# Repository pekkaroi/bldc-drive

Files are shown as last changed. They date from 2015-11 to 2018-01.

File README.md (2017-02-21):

# bldc-drive

This is a project developing a simple BLDC servo controller. It is based on an STM32F103 microcontroller.

Some parts, especially the PID control loop is based on development done by user mcm_xyz in cnczone.com forum. Thank you! Check the thread http://www.cnczone.com/forums/open-source-controller-boards/283428-cnc.html 

## Disclaimer
This software and hardware is provided "AS IS", WITHOUT ANY WARRANTY. The software is released under GPL v2. Authors accept no liability for any harm or loss resulting from use of this hardware or software.

## Authors & Contributors
* original Software by mcm_xyz from cnczone
* first Version of Hardware&Software in a Git-repo from pekkaroi via https://github.com/pekkaroi
* Schematic-additions and fork by Philipp Hörauf via https://github.com/Virtex7

## Firmware
Firmware is a work-in-progress (and will be for a while :), however following features are included:
* Trapezoidal BLDC commutation using either HALL sensors or quadrature encoder.
* Step+Dir input interface with PID position control loop.
* PWM+Dir input interface in velocity mode.
* USART communitacation for configuration. Configuration settings saved to flash memory.
* TODO: Motor Test Mode to simply activate a Motor with a fixed frequency, no encoder needed

### Update 1st May 2016
Some updates to the firmware. 
* ADC current limiting implemented. Appears to work OK
* I created a quick and ugly Python gui for tuning
* Updated the PID loop to have feedfoward coefficients FF1 and FF2 (like LinuxCNC). This means that the PID output can be adjusted by the requested speed and the requested acceleration. This made the PID tuning a lot easier for me at least, I'm able to get a motor to follow the requested position very well also during acceleration and during constant drive.

## Hardware:
First prototype hardware is built and it is working well. However, there are couple of known issues:
* 6n137 optocoupler is not officially supporting 3.3V supply voltage which is used in the board. In reality they seem to work, but the optocoupler should be changed or additional levelshifting circuitry added on next revision. Also, the optocoupler input circuit supports only push-pull-type encoder output. Many encoders seem to have open drain output. :(
* Few connectors in the layout missed solder stop openings. They were bit painfull to solder. :)
* The current amplifier INA27x connection is wrong. The IN+ and IN- should be swapped.

### STATUS QUO:

Second hardware revision with the above findings fixed is published. There are no known issues, two servo drives are succesfully driving my CNC router. Pics and videos to come..

### HARDWARE TODOs:

* verify all part-values into the schematic

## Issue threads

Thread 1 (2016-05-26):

PID error of the project

lemonhdu, 2016-05-26:
Lucky to see this impressive protect, it is with a good framwork. I have tested it in the step mode with an encoder of 4000 PPR. But when I adjust the input signal about 60KHz, that means the speed is under 1000 RPM, the pid error will decrease from 8800 to about 6500, then it will jump bigger and bigger till the biggest pid error.So during this, the sound is also bigger and bigger, why does it happen?
Thanks.

pekkaroi, 2016-05-26:
Thanks for you comment, you are probably the first one to test my code apart from myself!

There is a setting called "encoder_counts_per_step". What value did you have there? I've set it to 10 by default. This means that for each step pulse, the requested position will go +/-10. So if you did not change the default and  then give 60kHz input, the requested speed is already 9000rpm which may be too much? Are you able to run a motor with slower speed?

lemonhdu, 2016-05-27:
Yeah, I set  "encoder_counts_per_step" with 1, so the real speed should be 900 RPM. Didn't you encounter this problem?

pekkaroi, 2016-05-27:
No I haven't encountered that. However I'm not quite sure if I understand the problem you have. You say that the pid error will decrease when this happens. I don't know what that means.. Shouldn't the pid error be close to zero when the drive is functioning properly, that way the requested position is close to the actual position? How do you monitor the pid_error when you run the motor? I published my tuning Python gui last night. It can be used to monitor pid error and other things as well.

lemonhdu, 2016-05-30:
Thank you. Yes, the pid error decresed first and increase later, I am trying the make certain of it. I also believe the program is correct, otherwise the error will not decrease. The encoder I used before is 1000 PPR, if I understand correctly the program makes the frequency quadruple. Now I bought a new one with 3600 PPR, that may mean real PPR will be as much as 14400. I see the program brief "8096 PPR max at the moment", so whether this means this encoder can't be used at present. I print the parameters with usart. Congraduation to your tuner, it will be easier for debugging~

lemonhdu, 2016-05-31:
Pekka, have you tested the highest speed in the step mode with the encoder, and how about the torque performance? And what's the encoder's  PPR?

pekkaroi, 2016-05-31:
First, about the encoder PPR. The number specified with the encoder is usually telling that how many quadrature pulses you will get per rotation. Every quadrature pulse includes A line rising, B rising, A falling and B falling. My firmware will increment the counter at each of those events, so yes, the PPR (also called CPR) seen by my firmware is four times the rating you often see on the label of the encoder. However, I have also seen that some encoders have their rating already multiplied by four.

So far I've always used the default encoder_counts_per_step=10. I don't have a proper signal source to generate fast enough pulses to work without that multiplier. I have encoder with 1000 lines, i.e 4000 CPR. With this combination I've been able to reach >2000rpm. If you see that the error will start getting larger when you increase speed, I would assume that the step input is still read correctly by the driver but the motor is not able to follow for some reason? Are you using hall sensors or encoder for commutation? The commutation with encoder is not tested very well I have to say and that maybe starts to limit the performance at high speed.

lemonhdu, 2016-06-22:
Sorry to reply late, what you said is right. Now I have reached speed 3500 RPM with the new encoder. But when I try to increase the PID rate, the performance seem not to enhance. Theoretically, the PID rate should be as higher as possible, or not ?

pekkaroi, 2016-06-27:
Nice, 3500rpm sounds good. What do you mean by PID rate? The frequency at which the PID loop is run? To some extent it should improve the performance, but there are limits. The PWM frequency is set to ~20kHz, so when PID frequency starts to get close to this value, I think updating the PID more often has no effect at all and possibly even giving some unexpected results.

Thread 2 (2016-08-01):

Error while compiling with IAR ewarm utils.c

nionut, 2016-08-01:
I get this error at line 11 Error[Og006]: Error in inline assembly: "Error[41]: Bad label"
The error is in file utils.c  Any clue for debuging?

1   #include "utils.h"
2   #include <stddef.h>
3   #include <stdint.h>
4
5     void delay_ms(const uint32_t ms)
6    {
7
8        uint32_t ms2 = ms*STM32_CLOCK_HZ / 1000 / STM32_CYCLES_PER_LOOP;
9
10      asm volatile(" mov r0, %[ms2] \n\t"
11               "1: subs r0, #1 \n\t"
12               " bhi 1b \n\t"
13               :
14               : [ms2] "r" (ms2)
15               : "r0");
16    }

pekkaroi, 2016-08-01:
Hi. I have absolutely no experience with IAR, but according to short googling, it might be that IAR does not like the label "1" which is used in the assembly.

if you try to replace the lines
             "1: subs r0, #1 \n\t"
             " bhi 1b \n\t"

with
             "loop: subs r0, #1 \n\t"
             " bhi loop \n\t"

it might work. At least it compiles with GCC. Unfortunately I have no hardware in my hands right now to test the change. But could you check if this helps?

nionut, 2016-08-01:
I think that I need to instal Eclipse :-(
Error[Og006]: Error in inline assembly: "Error[54]: Expression can not be forward"
Error[Og006]: Error in inline assembly: "Error[54]: Expression can not be forward"

pekkaroi, 2016-08-01:
Ok, it really seems that IAR handles the asm() keyword differently to GCC. :( I'll try to find a way to implement the delay_ms in a better way without using assembly. I think the SysTick is the right way to go, I just need to learn how to use it.

pekkaroi, 2016-08-01:
I pushed a new version of utils.c. It is now implemented with systick and no assembly. You can try that. I'm afraid this is not the only problem with IAR though, but let's see?

nionut, 2016-08-02:
inline uint32_t millis (void)
{
  return ticks;        //ERROR
}

Error[Pe1031]: an entity with internal linkage cannot be referenced within an inline function with external linkage

pekkaroi, 2016-08-02:
Crap.. This is quite difficult as I cannot test it with IAR. :) It seems to do something with inline support on IAR. I have no clue if the inline declaration is even useful there, I followed an example on web on implementing the Systick delay quickly. You can try it out by simply removing the inline keyword..

nionut, 2016-08-02:
Nop a tried that and i get 101 Errors. IAR gives me headache.

pekkaroi, 2016-08-02:
Right.. I doubt it is the IAR that is causing the problem, it's just my lacking skill in software, the code is something that barely compiles in GCC with luck. :) Sadly I don't have a Windows computer to try with, it seems that there would be a trial version of IAR EWARM available..

nionut, 2016-08-02:
If You whant to install the trial version I can provide the activator serial for full

pekkaroi, 2016-08-03:
I installed the IAR on my girlfriends laptop and I think I made this compile now! (5 warnings are left) I had some serious stupidness on the header files, I'm surprised that GCC is so forgiving that it compiled this. I had some trouble with ST-Link on Windows, so I haven't tried the IAR image on hardware, but at least it compiles.

pekkaroi, 2016-08-03:
Hmm.. After getting the ST-Link to work, I have to say that this is more complicated than I thought. Now I am able to somehow start to run and debug the program, but as soon as first interrupt fires, I get a HardFault. And as I understand it, there is now something mixed with the startup code provided by IAR and the startup code included in my project. I am sorry to say, but I don't think I have enough interest to learn enough about IAR and it's proprietary startup code to really make this work.. :(

nionut, 2016-08-03:
Watch out for the optimizations level under Project-> Options->C/C++ Compiler->Optimizations  it has to be set to None
Then you have to write the path to the included files of your files not IAR in Project-> Options->C/C++ Compiler->Preprocessor->Additional include directories(one per line)
\src
\include
\system\include\cmsis
\system\include\stm32f1-stdperiph

And try to write USE_STDPERIPH_DRIVER
Project-> Options->C/C++ Compiler->Preprocessor->Defined symbols(one per line)

Make sure you select ST STM32F103C8 under Project-> Options->General Options->Target->Device

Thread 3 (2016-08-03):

STM32 PMSM FOC Software Development Kit - MC library

nionut, 2016-08-03:
Hello
What do you think it is possible to add PID position conttol of the mcm_xyz user from cnczone to this SDK. It auto generates code and project for IAR or Keil. From what i looked it is implemented only Speed and Torque in the ST Motor SDK.
FOC (Field Oriented Control) of 3-phase Permanent Magnet motors (PMSM, BLDC) brings increase torque ,efficiency, and reduce noise and torque ripple.
https://www.youtube.com/watch?v=yFecre8dacY

pekkaroi, 2016-08-05:
I'm quite sure it is possible, if it has some way to input speed, you need to add the pid loop and make the pid output control the speed. I read some papers and manuals about that devkit.. Personally I don't like that kind of stuff that much. I do all this for learning and that software hides most the learning. Of course, if you want to create a functional device quickly, I'm sure that is a good way to go.

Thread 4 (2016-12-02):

Dead time

lonelymyp, 2016-12-02:
I want to customize the firmware, for my motor control board, where can I configure the deadtime?

pekkaroi, 2016-12-02:
Hi, It is defined in pwm.h, the parameter BLDC_NOL (non-overlapping time)

lonelymyp, 2016-12-02:
Thank you.
and how this relates to stm32f10x_tim.c   TIM_BDTRInitStruct->TIM_DeadTime = 0x00;

pekkaroi, 2016-12-02:
in the pwm.c initialization, the TIM_DeadTime is set:
TIM_BDTRInitStructure.TIM_DeadTime = BLDC_NOL;

Closed 2016-12-02.

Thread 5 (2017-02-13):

some kind of TestMode missing

Virtex7, 2017-02-13:
I have started to read the code and looked at the gui as well but i think there is some kind of test mode missing, where you could just start the motor at very slow speed to test it without any encoder.

if I understand the code good enough, i will add such a mode to the software. i think that this will make development easier for beginners or people who have trouble with the encoder....

pekkaroi, 2017-02-13:
You are correct, there is no such mode and I agree, it might be useful in the beginning. Feel free to implement that. Personally I did that by modifying the code forcing the duty cycle to some small value, but that is not very elegant solution. :)

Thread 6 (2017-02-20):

schematic&layout

Virtex7, 2017-02-20:
Hi there!

I have taken a look at your schematic and layout, and have seen that you have created it in a kicad version older than 4.0. so i have forked the design and am actually migrating the project to kicad 4.0 and the new symbols.
if you like to merge it, i will create a pull request once i'm ready with the migrating process.
additionally i have deleted the older versions of schematic and layout, because there is git history and if you like you can pull older versions from there.

please do not migrate at the moment, because there is still work to do and migrating now will lead to more work for you :D

a list of parts and values that you have used in your prototypes would be neat, because they are not mentioned in the schematic...

sry. for something like fucked up grammar or missuse of words, I am from germany and so german is my first and main language...

pekkaroi, 2017-02-20:
Hi,

I think I have used quite recent git version of kicad, but I am not sure. I'll gladly accept a pull request if you get migration done. I have been working with revision 3 of the controller part. I'll publish that and also try to add component values there. But that will take a week at least, I am away from home for a while.

Virtex7, 2017-02-20:
ok.
then i will speed it up a bit and start my pull request when the schematic/layout work is done.
i thought about an older kicad version because of the old schematic symbols which are not in the current release... you will see it when it's done...

if you need any help regarding schematic/layouting just tell me, i am a far better electronics engineer than software developer :P

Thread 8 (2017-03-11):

port source code to STM32F407 please..

diobrandon, 2017-03-11:
port source code to STM32F407 please..
it would be more fast, and more easy to learn for us to develop

pekkaroi, 2017-04-12:
Thanks for the suggestion and sorry for delayed response. Personally I don't have hardware or time to port this to STM32F4-series, but it should not be a huge task as ST's standard peripheral lib is available for F4 as well.

Also, I don't fully agree with your arguments. Yes, you probably can run the F407 with larger clock frequency than F103, but in this application, it should not make any difference. The highest signal frequency involved here is the 20kHz PWM, the loops are running at few kHz. This is achievable with 8bit 8MHz MCU's as well, so going beyond 76MHz is rather pointless? Also, F103 is probably the cheapest and most available STM32 MCU there is, so I don't know how development would be easier with significantly more complex and expensive MCU?

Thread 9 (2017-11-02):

Newbie hint request

koepae, 2017-11-02:
Hi Pekka,

What tool/version was used for firmware?
I tried loading the project to STMworkbench but it reports error on not recognizing uint16_t

Should the components in KiCad schematic be connected?

Have you got any progress with posting videos?

Rgds,
Tapio

ps above in english for wider audience

pekkaroi, 2017-11-04:
Terve Tapio!

I have compiled this using Eclipse (Luna 4.4.0) and GCC (gcc-arm-none-eabi-4_8-2014q2) (https://gnu-mcu-eclipse.github.io/) on Debian Linux. Those versions are pretty old, I've had this environment working and have not dared to touch it. :) I'm not familiar with STMWorkbench, but according to what I just googled, it is also based on Eclipse&GCC, so should be pretty close.. uint16_t is defined in stdint.h I think, so it is strange that it is missing. It's been crossing my mind that I should try to upgrade my development environment to more recent versions. Right now I don't have time to really get to it, but I'll post updates if I manage to do that.

I didn't quite understand the question about KiCad. What do you mean connected?

Life has gotten a bit in the way of this hobby, so videos still don't exist.. I've been using the mill in practice every once in a while though, so it is just a matter of shooting that video..

BR,
Pekka

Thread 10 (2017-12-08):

Missing Binaries

pommen, 2017-12-08:
Hello Pekka!

Your project looks really  interesting to me, though I am struggling to get everything sorted with eclipse. Any chance you could add the binaries to the repository. Just flashing a .hex to a breakout board would do wonders to start prototyping.

Cheers
Peter

pekkaroi, 2017-12-08:
That's a good idea. I added them to the firmware directory. There are two, one compiled with option SINUSOID_DRIVE=1 and one with =0. There isn't too much documentation about what are the differences and unfortunately right now I need to go, so I cannot write too much, but SINUSOID_DRIVE=1 means that the motor is driven by three phase sinusoid voltages and the other uses six-step block commutation.

If you are successful in flashing and get a serial connection to it with the GUI or even get some motor spinning, I am very interested in hearing. I help as much as I can, but please don't expect too much, I've been busy with other stuff and I am starting to forget how this piece of code even worked. :)

pommen, 2017-12-08:
That sounds great, Thanks!
First step is to make some crude proto and try to get a motor spinning, I will keep you updated on my progress.

Best regards
Peter

lonelymyp, 2017-12-08:
I used this manual to set up eclipse https://www.carminenoviello.com/2014/12/28/setting-gcceclipse-toolchain-stm32nucleo-part-1/
I was able to compile, upload and get communication with the controller.

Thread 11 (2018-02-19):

BOM

rklosinski, 2018-02-19:
Is there a BOM available?

pekkaroi, 2018-02-20:
Hi,
I haven't done any proper BOM for this, unfortunately even some component values may be missing from the schematic, but most of the components can be exported from KiCad.. I have always drawn the schematic based on the components I have available, so generating a BOM for ordering stuff has not been necessary..

rklosinski, 2018-02-20:
OK. Thanks for the reply. I redrew the schematic and added components using altium dxp. The design was changed a bit to suit my needed.

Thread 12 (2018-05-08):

NOOB guide /Help

Wintertod, 2018-05-08:
can you tell me and maybe others how to use this? how does configuring the servo work? I cant start the GUI when opening with python.

tecfacet, 2018-06-19:
With field oriented control, don't you have to change the commutation tables to sine?  I wish I knew what it would take to change to sine.  I would like to compare sine to trapezoid.

pekkaroi, 2018-06-19:
I have implemented sinusoid drive in this firmware even though not very carefully tested it. Selection between sinusoid or trapezoid is made in file configuration.h. Sine commutation doesn't use hall sensors at all, only encoder to generate the commutation voltages. pwm.c contains the actual implementation of the commutation, that could be a starting point for studying the differences between the methods.

tecfacet, 2018-06-19:
I looked at the code and saw the sine calls.  I will study the code.  On another note, you have mentioned that you recognize the shortfalls of your design..  Can you share some things with me that you feel are not working well or sub standard compared to a commercial servo amp?  I might be able to contribute some code to you.

tecfacet, 2018-06-19:
I also was thinking about using a different method to tune the drive.  Where in the code is the message payload for the tuning software.  I should find this myself but I am taking advantage of you  lol

tecfacet, 2018-06-19:
I have one last question. ... What is the development environment?  Will the software compile under gcc and eclipse?    Thank you.

Wintertod, 2018-06-19:
I had real problems with that too. IIrc he mentioned somewhere that he used eclipse, but a older version. Its a real pain to install the toolchains and stuff. Now I program stm32f103 with the arduino ide. Do you know a ide which is good with stm chips?

tecfacet, 2018-06-19:
I am going to install a newer version of eclipse and gcc.  I used both at Honeywell for Arm cores.  I will let you know how I make out.

Wintertod, 2018-06-19:
So sou know how Good oh performs with dc Motors? I've seen the position accuracy is around 10 encoder steps. Do you have any jmc servos to compare to? And do you know a better alternative for dc servos, like elm Chan?

tecfacet, 2018-09-24:
Hello Again.
Do you have any spare boards for your servo amp?
I am working on some code and would like to try it on your design.
Thank you,
Roger

    On Tuesday, June 19, 2018, 12:01:53 AM MDT, pekkaroi <notifications@github.com> wrote:

I have implemented sinusoid drive in this firmware even though not very carefully tested it. Selection between sinusoid or trapezoid is made in file configuration.h. Sine commutation doesn't use hall sensors at all, only encoder to generate the commutation voltages. pwm.c contains the actual implementation of the commutation, that could be a starting point for studying the differences between the methods.

—
You are receiving this because you commented.
Reply to this email directly, view it on GitHub, or mute the thread.

pekkaroi, 2018-09-27:
Hello. I don't have any finished spare boards. I probably have some bare PCBs somewhere, but quite frankly, shipping the boards from here is probably more expensive than ordering new from China.. And also, if you are willing to try any sort of current control (and I think you should), my board design is not very good. I realized that as the big filtering capacitors are after the current sense resistor, the current sensor is low pass filtered very heavily and thus not suitable for using in the control loop. New board design should be done, but I havent found time to complete it..

tecfacet, 2018-09-27:
I was thinking about doing a FOC design with dual current sense resistors.
What kind of performance are you seeing with your router?
Can you maintain a decent accuracy?  What is lacking, if anything?
Thank you,
Roger 
    On Thursday, September 27, 2018, 1:46:50 AM MDT, pekkaroi <notifications@github.com> wrote:

Hello. I don't have any finished spare boards. I probably have some bare PCBs somewhere, but quite frankly, shipping the boards from here is probably more expensive than ordering new from China.. And also, if you are willing to try any sort of current control (and I think you should), my board design is not very good. I realized that as the big filtering capacitors are after the current sense resistor, the current sensor is low pass filtered very heavily and thus not suitable for using in the control loop. New board design should be done, but I havent found time to complete it..

—
You are receiving this because you commented.
Reply to this email directly, view it on GitHub, or mute the thread.

pekkaroi, 2018-09-27:
Very good - dual sensing is definitely the way to go. And FOC. I'd like to implement that some day as well.

In my router, the performance is rather good. I have it in closed loop control with LinuxCNC and I'd say that the accuracy of the motor control stays within 0.01mm during all movements. That is way more than the accuracy of my flexy DIY router. The motors are some Technic motors with 4000cnt/rev encoders.

I then tried to use the drive with my 3d printer and brought some cheap BLDC motors in Nema17 size. I simply was not able to tune the drive to work pretty much at all.. That's pretty much where I'm left at, but haven't got time to investigate further.

Wintertod, 2018-09-27:
For 3d printing I would go with DC motors, especially the 775 60W and 895
360W motors work really good. They go from 3500 to 12000rpm at 36v. I
dropped the whole all in one servo drive concept, there are ready made
bts7960 h bridges of wich 2 get you 4 phase (3 for bldc). Form factor of
the 775 3500 rpm motor is size wise compatible with nema17, i testet 2kg on
a 20t gt2 pulley vertical load. My encoder is a as5040 with 512/1024
interpolated steps. I could tune it to +-1 step accuracy which is
sufficient for 3d printing ffm. Bts79xx are really neat they aee complete
half bridges with current sens and protection at 43A up to 90A at 36v, 2,6€
a piece when you want to build your own 3 phase drive. But really the h
bridge in 43a is on eBay for 5€ which is cheaper than the bts ics. BTW
everything under a certain power I wouldn't recommend bldc,they are too
expensive or not good as a servo.

Another question, have you guys ever thought about implementing sin/cos
encoders? They are insane, I mean a 100s/r encoder interpolated at 10bit
already has 100000ppr, I have a project at work where I have a 1024 sine
/revolution interpolated at 16bit with a native resolution of 67108864ppr.
I thought that we could build them in (low quality) relatively easy, I mean
at 50 or 100 lines with led photodiode and interpolated with 10bit that's
50 to 100k pulses/revolution.

Right now my cost for a 20Ncm servo system is 21€, 7€ the 775 motor 5€ the
h bridge 2€ the stm32f103 and 5€ the as5040 2€ a pcb with headers and LEDs

A rather long reply... On the pictures you see the motor, the 4 holes are
the nema17 holes.

pekkaroi <notifications@github.com> schrieb am Do., 27. Sep. 2018, 19:44:

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

tecfacet, 2018-09-27:
Can you send or give me a picture of how you are using Linuxcnc for tuning?

I will make PCBs if I can get them to work with LinuxCNC and PMSM.

Can someone post a flowchart or picture?

Thank you,

tecfacet, 2018-09-27:
Wintertod ...
Can you give me more information on your servo system?
What firmware?  How are you tuning?
Thank you,
Roger
    On Thursday, September 27, 2018, 1:46:50 AM MDT, pekkaroi <notifications@github.com> wrote:

Hello. I don't have any finished spare boards. I probably have some bare PCBs somewhere, but quite frankly, shipping the boards from here is probably more expensive than ordering new from China.. And also, if you are willing to try any sort of current control (and I think you should), my board design is not very good. I realized that as the big filtering capacitors are after the current sense resistor, the current sensor is low pass filtered very heavily and thus not suitable for using in the control loop. New board design should be done, but I havent found time to complete it..
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
tecfacet, 2018-09-28:
There are two parts of the equation.
1.  The UI for tuning -  Is this what you rewrote and sent to me?
2.  The servo code.  I believe this is an Eclipse project.  Thoughts?
Sorry for all of the questions .. I am just trying to get up to speed as quick as possible.
Than you.
By the way, where are you located?  I live in New Zealand but currently I am in New Mexico, USA.
    On Friday, September 28, 2018, 9:26:40 AM MDT, Wintertod <notifications@github.com> wrote:

Well the problem with this software is, it's just not mainstream enough. When you are a standard windows user u don't nessesary have python. It took me 6h to sort every problem out till I had a working ui. 2 I needed a usb to serial interface even though stm has usb. I didn't even get to use pekkarois software in the end because i don't have the time to setup a different work environment from scratch which will take days, at least on the first time.
I know it's a bit harder to search for readily available parts online. But not everyone wants to get a reflow oven an in the end I can get working servos for 80€, no need to invest countless hours and more money to get an experimental product.
Like I said, the bridge is just called bts7960.
I ordered a 895 dc motor today to test it. 5cm diameter is still in nema 17 format, the 5mm shaft is ideal for pulleys and it got an 5mm 2nd shaft for encoder. Seller says peak torque at 24v 16a is 9,8kg/cm but I calculated more like 5kg/cm torque. The speed of 6000rpm should be good too, since it's important. With my system right now I'm able to archive up to 8m/s. With the upgraded motor I'm planning to archive 10m/s with accuracy of 0,04mm and the capability to move 3-4kg loads.
Sorry for the blocked file access, first time sharing with gdrive.

—
You are receiving this because you commented.
Reply to this email directly, view it on GitHub, or mute the thread.

Wintertod, 2018-09-28:
The project is the predecessor of pekkarois. It is as far as I can tell not
good written. Information for it were basically non existent and project is
abbadonend. The author is a guy called Mirai iirc.
I'm located in Germany and am a ee for automation, I usually programm in c#
on visual studio, c in arduino because it's an easy environment to use.
For work I mainly use Siemens plc.
The files I send you are a coocox project, I at least got it to compile...
Sadly Coocox is dead
I never tried bldc controll with this code, I have some bldc motors but
none are suitable for precision control. And as I said for low power
applications I would go with DC motors since they are cheaper, controll is
simpler, there are many available. I don't know I you know jmc servos, you
can Google them, they are good mid range bldc servos with 0,55nm and 300%
5s overload capability. In the high power range, buy a asynchronous motor,
put a encoder on it and get an stmbl drive the code for that one is pretty
good they controll a Mitsubishi robot with it.
In the end what I did on this project is mainly sorting of information and
hardware research and design, of wich I can't share all right now and what
I shared is all that's needed anyway.
What is your goal and your budget? My goal was a modular servo that
everyone can build when they have 30€ and access to ebay/aliexpress, I
wanted a controller where you can connect any incremental encoder and motor
driver to get a working system. The code right now works OK, I can controll
the servo with a step/dir impulse from grbl on a arduino.
Don't know if you can use much of it, but I could assist with hardware
design in solid works, pcb design with eagle (even though I don't want to
design a complex pcb) I probably can design a gui in visual studio.

<notifications@github.com> schrieb am Fr., 28. Sep. 2018, 17:36:

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

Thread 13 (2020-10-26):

DC brushed motor version

kamilkamil1, 2020-10-26:
Hi, I would ask about possibility of implementation code for DC brushed motors. I tried change pwm.c file with pwm_Comutate to simple fixed BH1, BL1 parameters but its not work. Pekka please indicate me direction which I should focuse.

Thanks a lot

Kamil.

pekkaroi, 2020-10-28:
Hi,

My first recommendation would be to look for projects that already implement this. First one based on a quick search:
- https://github.com/ottoragam/Tarocco

I haven't used brushed DC motors in servo applications ever, but I think it needs two half bridges, not only one. This is because you want to drive current to both directions, so you need to connect the motor between two of the three outputs and then modify the control so that the PWM generation scheme is changed only when changing the direction of the current. There are probably many ways to drive it, I'd most probably try forcing phase1 high and generating PWM on low side of phase2 when driving forward and forcing phase2 high and generating PWM on phase1 low side when reversing.

kamilkamil1, 2020-11-05:
Thank you for your response Pekka,
I will change the BH1 BH2 BL1 BL2, but every thing should stay as is ? what about Hall timer and initiation of halls? can I disable this ?

I have another question regarding gui to set parameters, there are some exe file as aplication for windows ?

Thank you one more time.

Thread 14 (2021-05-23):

please tell me what does encoder_poles mean

y5664579, 2021-05-23:
Hi,
Excellent open source project.I try to run it everything is fine but  I don't know the specific meaning of encoder_poles.
It refers to the motor coil pair？It refers to the encoder subdivision？Or something else？
I read the code, but only in one calculation.Please tell me what it means.
Thanks a lot
y5664579.

pekkaroi, 2021-05-24:
Hi. You are correct, it refers to the number of pole pairs in the motors. The name seems to be stupid.. :)

y5664579, 2021-05-24:
> Hi. You are correct, it refers to the number of pole pairs in the motors. The name seems to be stupid.. :)

------
So encoder_poles = all coils / 3
Is it right?
BTW what does commutation_offset mean?
thx for your reply.

artayasa, 2024-01-11:
> Hi. You are correct, it refers to the number of pole pairs in the motors. The name seems to be stupid.. :)

Hi sir, why the GUI i cannot open sir? i already instal newer phyton sir.

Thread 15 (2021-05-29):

> Hi. You are correct, it refers to the number of pole pairs in the motors. The name seems to be stupid.. :)

y5664579, 2021-05-29:
> Hi. You are correct, it refers to the number of pole pairs in the motors. The name seems to be stupid.. :)

------
So encoder_poles = all coils / 3
Is it right?
BTW what does commutation_offset mean?
thx for your reply.

_Originally posted by @y5664579 in https://github.com/pekkaroi/bldc-drive/issues/14#issuecomment-846818567_

pekkaroi, 2021-05-29:
Hi. Sorry for not replying earlier, I am not very active in github nowadays.. If I remember correctly, with commutation_offset you can modify the position where the commutation happens, when using encoder and not hall sensors.

Closed 2021-05-29.

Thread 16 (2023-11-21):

It posible for pmsm servo 220v 5A???

artayasa, 2023-11-21:
Hii iam very apriciate to your project.

For now i looking like this driver for my pmsm servo 220v 5A. With ABZ encorder 2500ppr.
It is posible to used??
And this already suport step/dir interface right???
I will coustem the driver and igbt
With this chip IKCM30F60GA. (Already include driver igbt, you can check the data sheet)
Iam also want to used for my cnc. If u have time i wait for the answere🙏🙏🙏

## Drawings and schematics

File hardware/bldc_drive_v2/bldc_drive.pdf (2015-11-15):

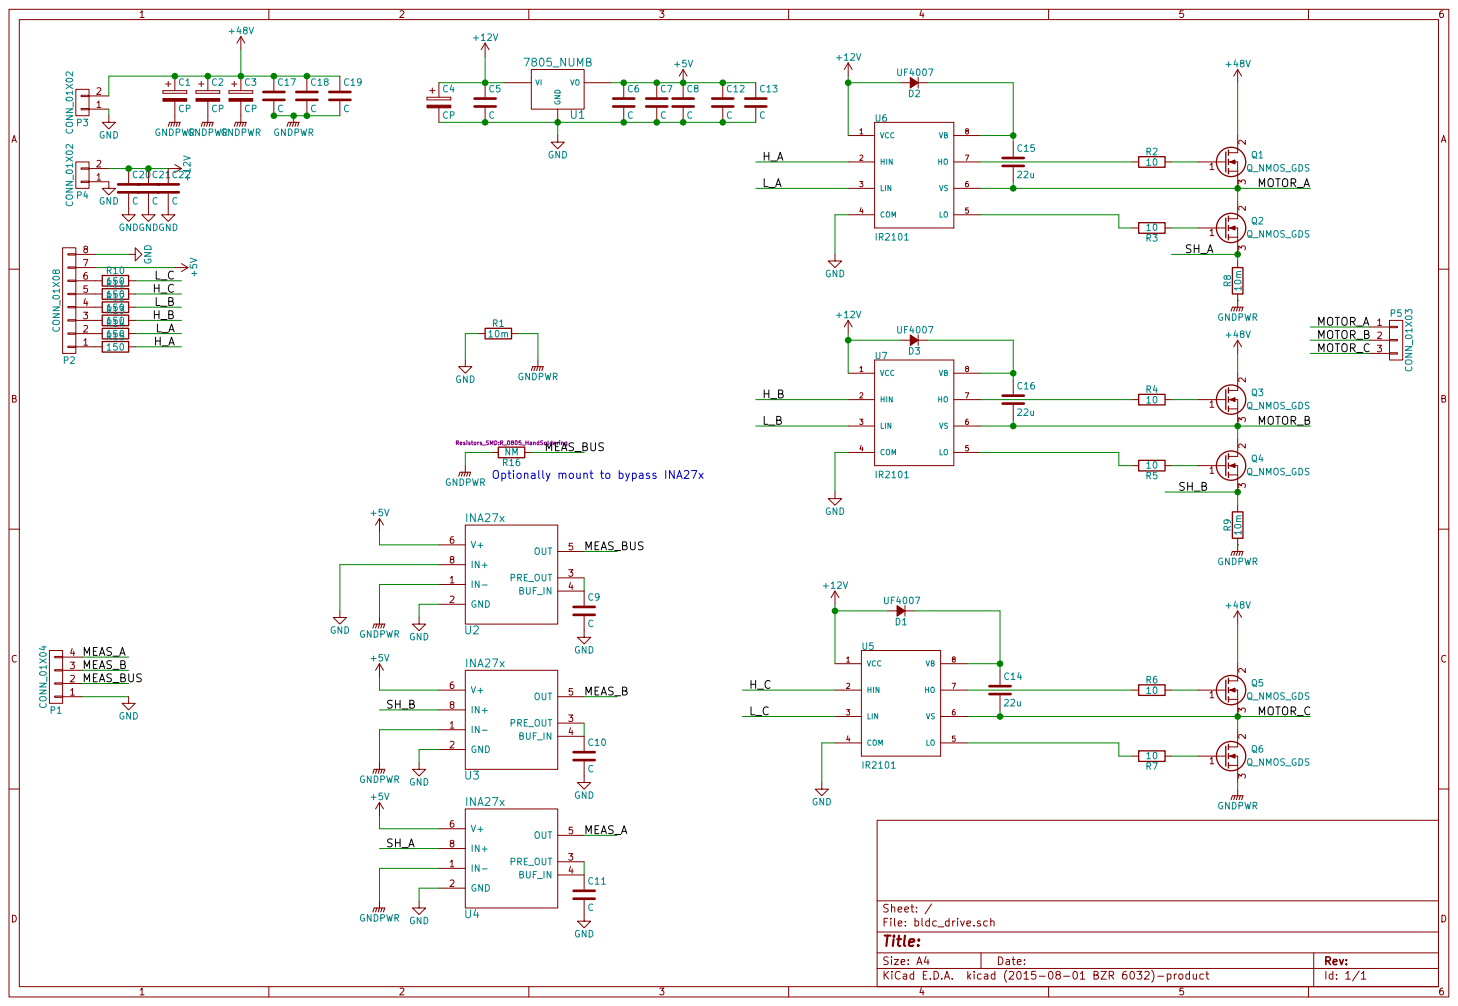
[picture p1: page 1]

Optionally mount to bypass INA27x

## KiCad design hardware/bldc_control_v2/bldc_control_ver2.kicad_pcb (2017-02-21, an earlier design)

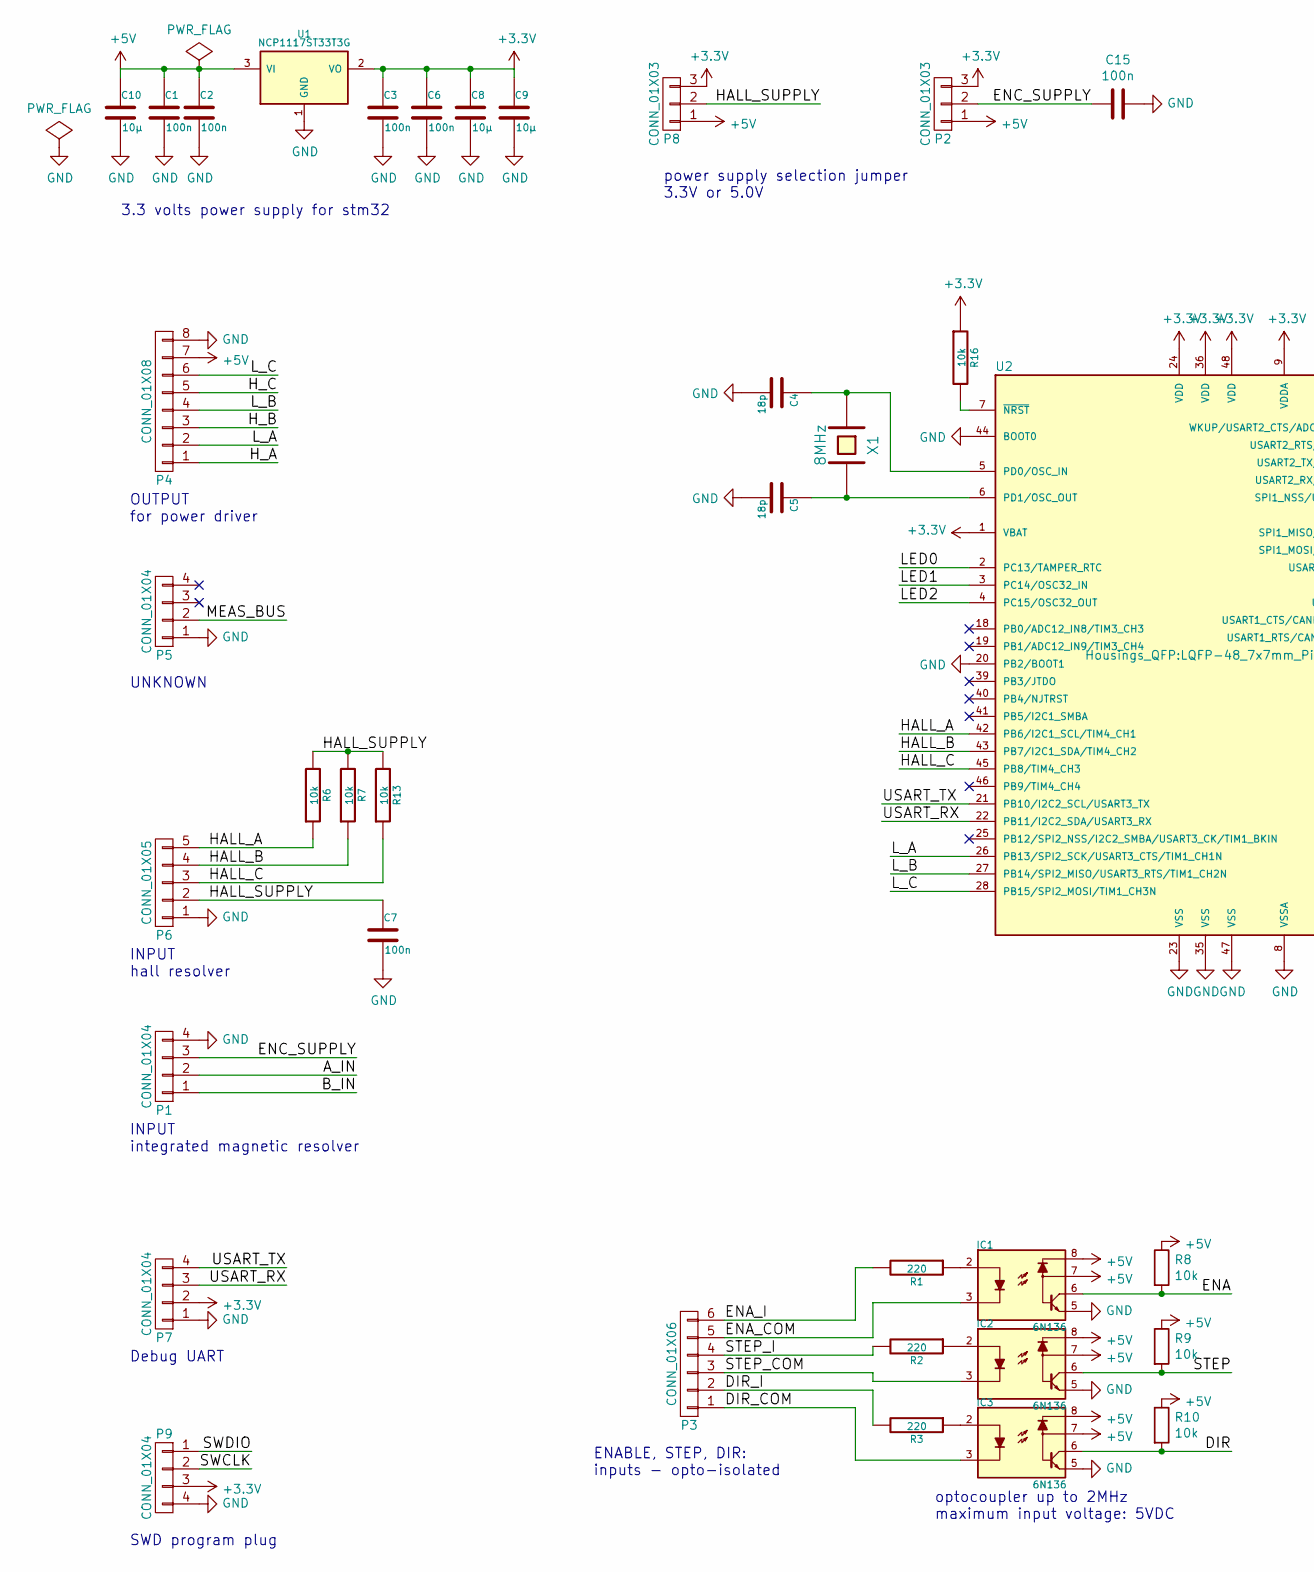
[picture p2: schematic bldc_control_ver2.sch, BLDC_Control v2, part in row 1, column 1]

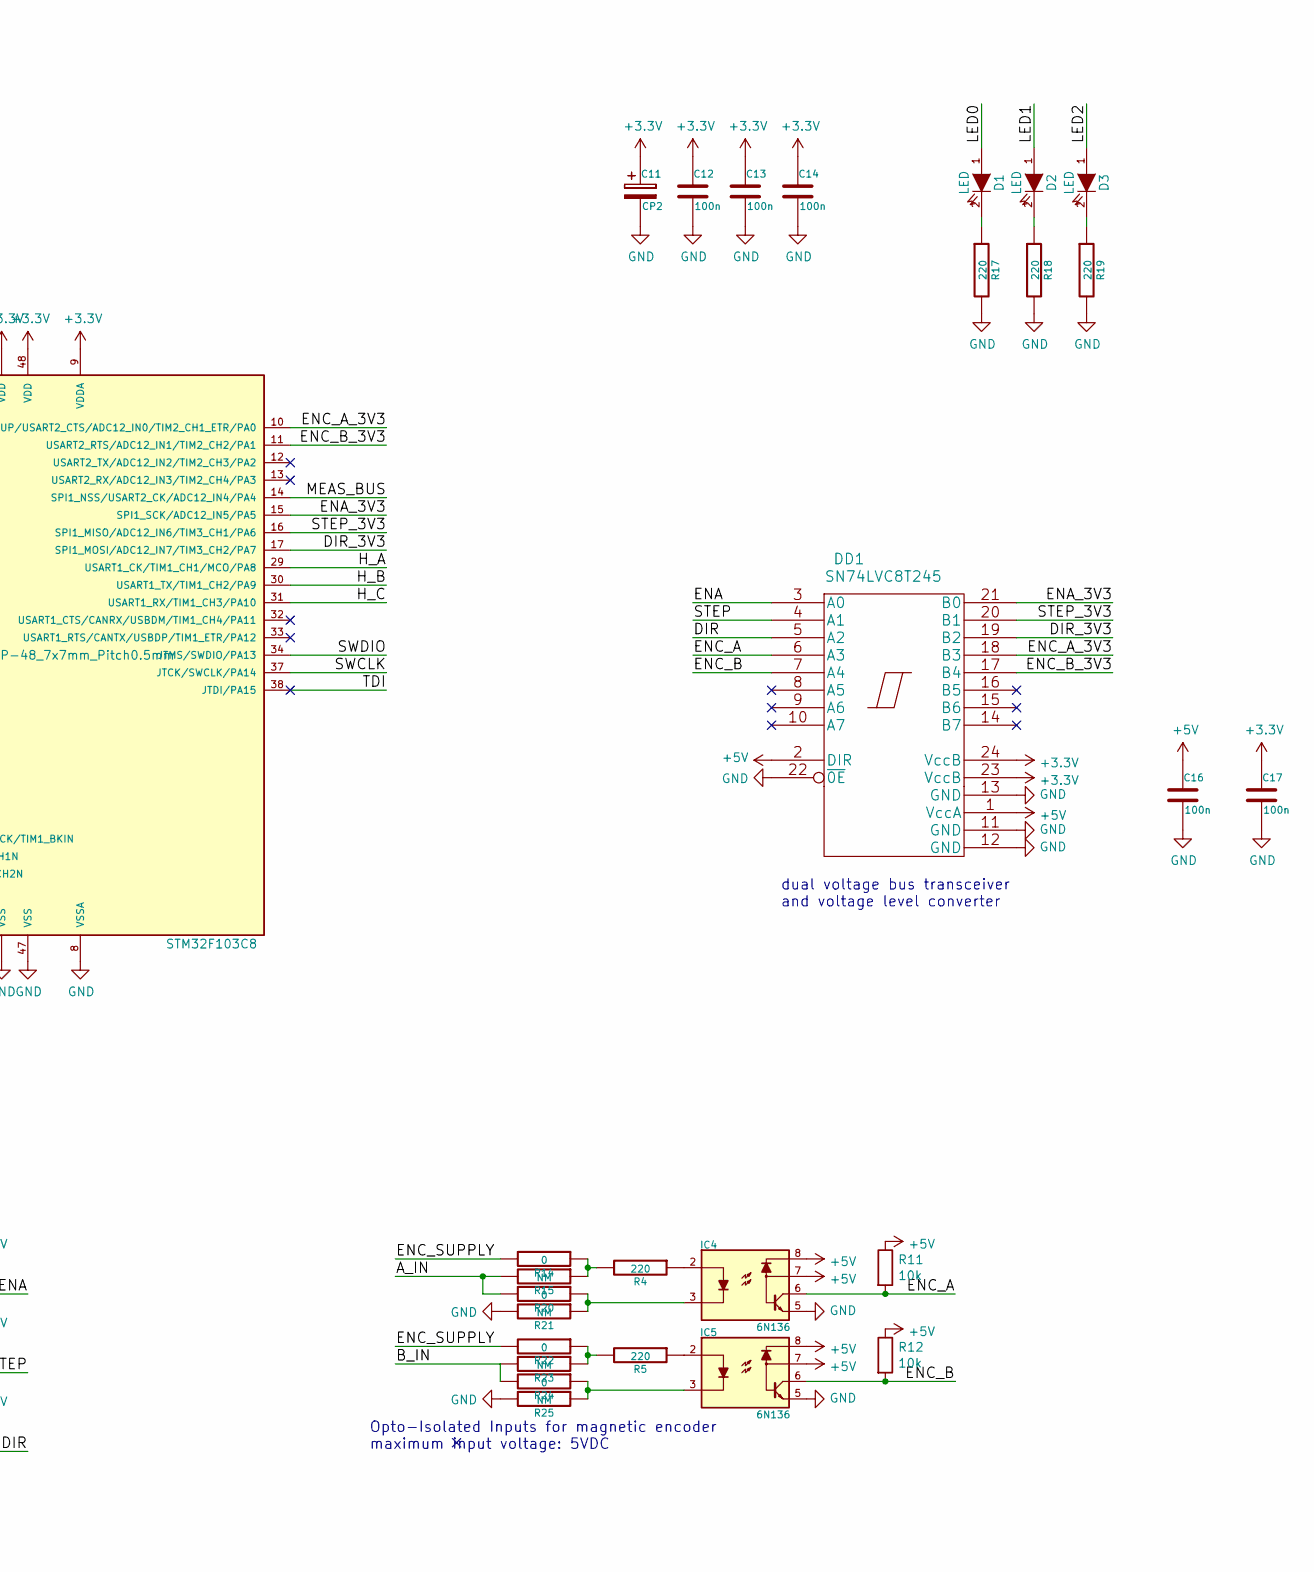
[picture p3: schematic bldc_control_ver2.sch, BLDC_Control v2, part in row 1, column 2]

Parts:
C1, C2, C3, C6, C7, C12, C13, C14, C15, C17: 100n; C_0603
C4, C5: 18p; C_0603
C8, C9, C10: 10µ; C_0805
C11: CP2; TantalC_SizeC_EIA-6032_Reflow
C16: 100n; C_1206
D1, D2, D3: LED; LED_0603
DD1: SN74LVC8T245; SSOP-24_5.3x8.2mm_Pitch0.65mm
IC1, IC2, IC3, IC4, IC5: 6N136; SMD-8
P1: CONN_01X04; JST_PH_B4B-PH-K_04x2.00mm_Straight
P2, P8: CONN_01X03; Pin_Header_Straight_1x03
P3: CONN_01X06; Pin_Header_Straight_1x06
P4: CONN_01X08; JST_PH_B8B-PH-K_08x2.00mm_Straight
P5, P7: CONN_01X04; Pin_Header_Straight_1x04
P6: CONN_01X05; JST_XH_B05B-XH-A_05x2.50mm_Straight
P9: CONN_01X04; jst-ph-JST-PH4
R1, R2, R3, R4, R5, R17, R18, R19: 220; R_0603
R6, R7, R8, R9, R10, R11, R12, R13, R16: 10k; R_0603
R14, R20, R22, R24: 0; R_0603
R15, R21, R23, R25: NM; R_0603
U1: NCP1117ST33T3G; SOT-223-3Lead_TabPin2
U2: STM32F103C8; LQFP-48_7x7mm_Pitch0.5mm
X1: 8MHz; Crystal_HC49-SD_SMD

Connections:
+3V3: C3.1, C6.1, C8.1, C9.1, C11.1, C12.1, C13.1, C14.1, C17.1, DD1.23 (VccB), DD1.24 (VccB), P2.3, P7.2, P8.3, P9.3, R16.1, U1.2 (VO), U2.1 (VBAT), U2.9 (VDDA), U2.24 (VDD), U2.36 (VDD), U2.48 (VDD)
+5V: C1.1, C2.1, C10.1, C16.1, DD1.1 (VccA), DD1.2 (DIR), IC1.7, IC1.8, IC2.7, IC2.8, IC3.7, IC3.8, IC4.7, IC4.8, IC5.7, IC5.8, P2.1, P4.7, P8.1, R8.1, R9.1, R10.1, R11.1, R12.1, U1.3 (VI)
/A_IN: P1.2, R15.2, R20.2
/B_IN: P1.1, R23.2, R24.2
/DIR: DD1.5 (A2), IC3.6, R10.2
/DIR_3V3: DD1.19 (B2), U2.17 (SPI1_MOSI/ADC12_IN7/TIM3_CH2/PA7)
/DIR_COM: IC3.3, P3.1
/DIR_I: P3.2, R3.2
/ENA: DD1.3 (A0), IC1.6, R8.2
/ENA_3V3: DD1.21 (B0), U2.15 (SPI1_SCK/ADC12_IN5/PA5)
/ENA_COM: IC1.3, P3.5
/ENA_I: P3.6, R1.2
/ENC_A: DD1.6 (A3), IC4.6, R11.2
/ENC_A_3V3: DD1.18 (B3), U2.10 (WKUP/USART2_CTS/ADC12_IN0/TIM2_CH1_ETR/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)
/ENC_B: DD1.7 (A4), IC5.6, R12.2
/ENC_B_3V3: DD1.17 (B4), U2.11 (USART2_RTS/ADC12_IN1/TIM2_CH2/PA1)
/ENC_SUPPLY: C15.2, P1.3, P2.2, R14.2, R22.2
/HALL_A: P6.5, R6.1, U2.42 (PB6/I2C1_SCL/TIM4_CH1)
/HALL_B: P6.4, R7.1, U2.43 (PB7/I2C1_SDA/TIM4_CH2)
/HALL_C: P6.3, R13.1, U2.45 (PB8/TIM4_CH3)
/HALL_SUPPLY: C7.1, P6.2, P8.2, R6.2, R7.2, R13.2
/H_A: P4.1, U2.29 (USART1_CK/TIM1_CH1/MCO/PA8)
/H_B: P4.3, U2.30 (USART1_TX/TIM1_CH2/PA9)
/H_C: P4.5, U2.31 (USART1_RX/TIM1_CH3/PA10)
/LED0: D1.1 (A), U2.2 (PC13/TAMPER_RTC)
/LED1: D2.1 (A), U2.3 (PC14/OSC32_IN)
/LED2: D3.1 (A), U2.4 (PC15/OSC32_OUT)
/L_A: P4.2, U2.26 (PB13/SPI2_SCK/USART3_CTS/TIM1_CH1N)
/L_B: P4.4, U2.27 (PB14/SPI2_MISO/USART3_RTS/TIM1_CH2N)
/L_C: P4.6, U2.28 (PB15/SPI2_MOSI/TIM1_CH3N)
/MEAS_BUS: P5.2, U2.14 (SPI1_NSS/USART2_CK/ADC12_IN4/PA4)
/STEP: DD1.4 (A1), IC2.6, R9.2
/STEP_3V3: DD1.20 (B1), U2.16 (SPI1_MISO/ADC12_IN6/TIM3_CH1/PA6)
/STEP_COM: IC2.3, P3.3
/STEP_I: P3.4, R2.2
/SWCLK: P9.2, U2.37 (JTCK/SWCLK/PA14)
/SWDIO: P9.1, U2.34 (JTMS/SWDIO/PA13)
/TDI: U2.38 (JTDI/PA15)
/USART_RX: P7.3, U2.22 (PB11/I2C2_SDA/USART3_RX)
/USART_TX: P7.4, U2.21 (PB10/I2C2_SCL/USART3_TX)
GND: C1.2, C2.2, C3.2, C4.2, C5.2, C6.2, C7.2, C8.2, C9.2, C10.2, C11.2, C12.2, C13.2, C14.2, C15.1, C16.2, C17.2, DD1.11 (GND), DD1.12 (GND), DD1.13 (GND), DD1.22 (~0E), IC1.5, IC2.5, IC3.5, IC4.5, IC5.5, P1.4, P4.8, P5.1, P6.1, P7.1, P9.4, R17.2, R18.2, R19.2, R21.2, R25.2, U1.1 (GND), U2.8 (VSSA), U2.20 (PB2/BOOT1), U2.23 (VSS), U2.35 (VSS), U2.44 (BOOT0), U2.47 (VSS)
unnamed: C4.1, U2.5 (PD0/OSC_IN), X1.1
unnamed: C5.1, U2.6 (PD1/OSC_OUT), X1.2
unnamed: D1.2 (K), R17.1
unnamed: D2.2 (K), R18.1
unnamed: D3.2 (K), R19.1
unnamed: IC1.2, R1.1
unnamed: IC2.2, R2.1
unnamed: IC3.2, R3.1
unnamed: IC4.2, R4.1
unnamed: IC4.3, R20.1, R21.1
unnamed: IC5.2, R5.1
unnamed: IC5.3, R24.1, R25.1
unnamed: R4.2, R14.1, R15.1
unnamed: R16.2, U2.7 (~NRST)
unnamed: R5.2, R22.1, R23.1

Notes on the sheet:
3.3 volts power supply for stm32
SWD program plug
Debug UART
INPUT hall resolver
dual voltage bus transceiver and voltage level converter
power supply selection jumper 3.3V or 5.0V
ENABLE, STEP, DIR: inputs - opto-isolated
optocoupler up to 2MHz maximum input voltage: 5VDC
INPUT integrated magnetic resolver
Opto-Isolated Inputs for magnetic encoder maximum input voltage: 5VDC
OUTPUT for power driver
UNKNOWN

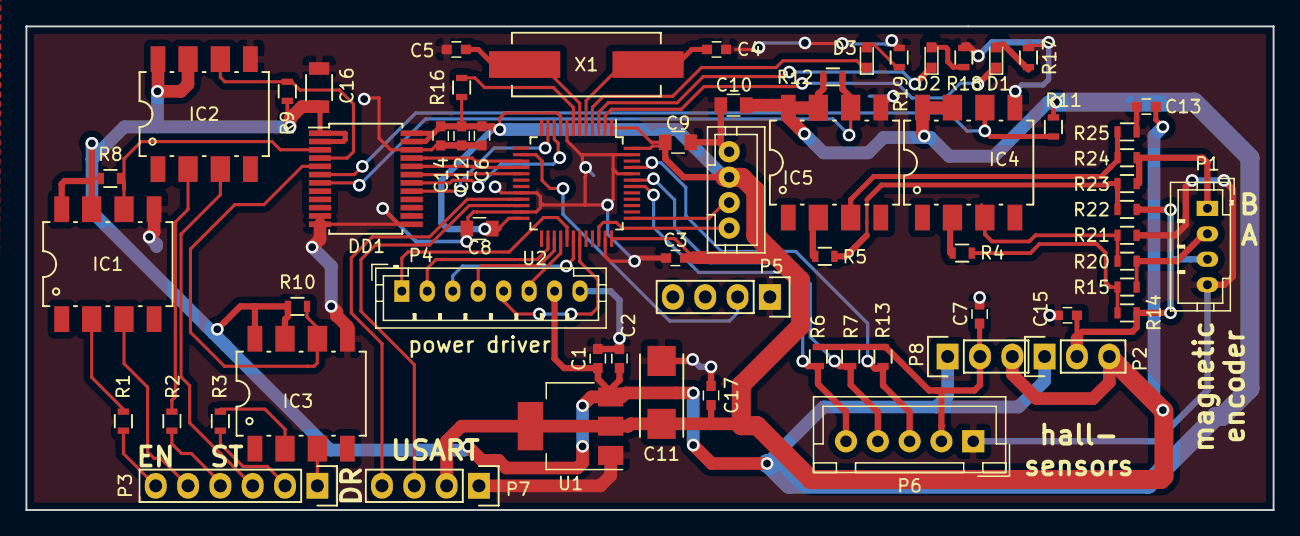
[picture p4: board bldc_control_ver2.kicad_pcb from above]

Board: 2 copper layers, 98.0 x 38.0 mm, 63 parts (0 on the bottom side), 55 nets.

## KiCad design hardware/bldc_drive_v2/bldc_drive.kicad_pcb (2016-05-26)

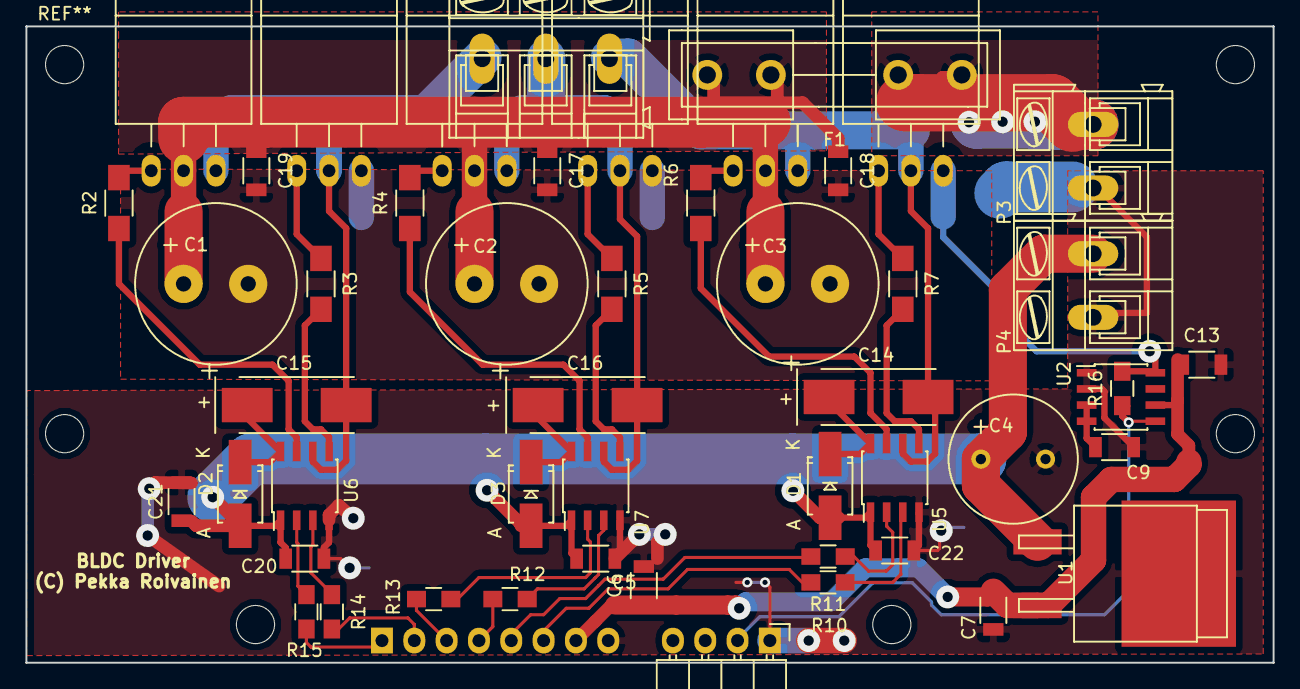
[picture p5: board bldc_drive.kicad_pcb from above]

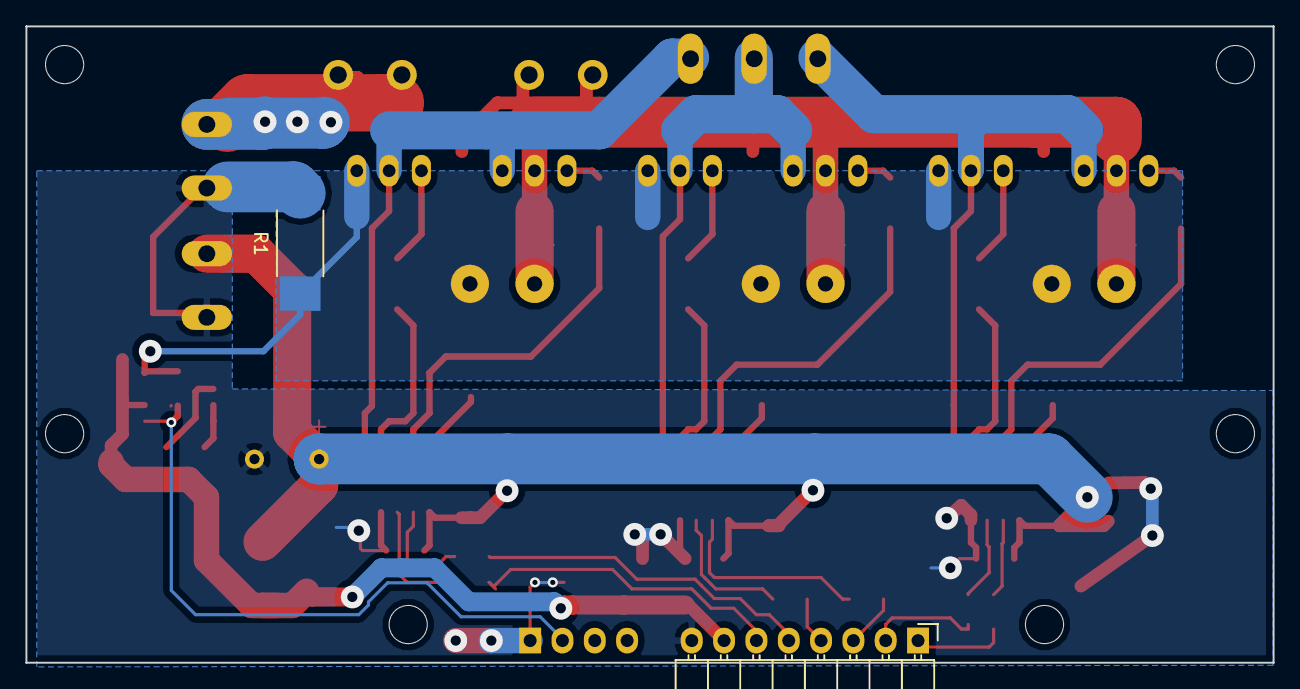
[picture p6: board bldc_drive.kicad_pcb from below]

Board: 2 copper layers, 98.0 x 50.0 mm, 52 parts (2 on the bottom side), 38 nets.

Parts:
C1, C2, C3: CP; Elko_vert_25x12.5mm_RM5
C4: CP; Elko_vert_20x10mm_RM5
C5, C6, C7, C9, C13, C17, C18, C19, C20, C21, C22: C; C_1206
C14, C15, C16: 22u; TantalC_SizeD_EIA-7343_HandSoldering
D1, D2, D3: UF4007; SMA_Handsoldering
F1: 10A?; Fuseholder5x20_horiz_open_inline_Type-I
P1: CONN_01X04; Pin_Header_Angled_1x04
P2: CONN_01X08; Pin_Header_Angled_1x08
P3, P4: CONN_01X02; AK300-2
P5: CONN_01X03; AK300-3
Q1, Q2, Q3, Q4, Q5, Q6: Q_NMOS_GDS; TO-220_Neutral123_Horizontal
R1: 10m; R_2512_HandSoldering
R2, R3, R4, R5, R6, R7: 10; R_1206_HandSoldering
R10, R11, R12, R13, R14, R15: 150; R_0805_HandSoldering
R16: NM; R_0805_HandSoldering
U1: 7805_NUMB; sot404
U2: INA27x; SOIC-8_3.9x4.9mm_Pitch1.27mm
U5, U6, U7: IR2101; SOIC-8_3.9x4.9mm_Pitch1.27mm

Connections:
+5V: C6.1, C7.1, C13.1, P2.7, U1.3, U2.6
+12V: C4.1, C5.1, C20.1, C21.1, C22.1, D1.2, D2.2, D3.2, P4.2, U1.1, U5.1, U6.1, U7.1
+48V: C1.1, C2.1, C3.1, C17.1, C18.1, C19.1, F1.2, Q1.2, Q3.2, Q5.2
/H_A: R15.1, U6.2
/H_B: R13.1, U7.2
/H_C: R11.1, U5.2
/L_A: R14.1, U6.3
/L_B: R12.1, U7.3
/L_C: R10.1, U5.3
/MEAS_BUS: P1.2, R16.1, U2.5
/MOTOR_A: C15.2, P5.1, Q1.3, Q2.2, U6.6
/MOTOR_B: C16.2, P5.2, Q3.3, Q4.2, U7.6
/MOTOR_C: C14.2, P5.3, Q5.3, Q6.2, U5.6
GND: C4.2, C5.2, C6.2, C7.2, C9.2, C13.2, C20.2, C21.2, C22.2, P1.1, P2.8, P3.1, P4.1, R1.2, U1.2, U2.1, U2.2, U5.4, U6.4, U7.4
GNDPWR: C1.2, C2.2, C3.2, C17.2, C18.2, C19.2, Q2.3, Q4.3, Q6.3, R1.1, R16.2, U2.8
unnamed: C9.1, U2.3, U2.4
unnamed: C14.1, D1.1, U5.8
unnamed: C15.1, D2.1, U6.8
unnamed: C16.1, D3.1, U7.8
unnamed: F1.1, P3.2
unnamed: P2.1, R15.2
unnamed: P2.2, R14.2
unnamed: P2.3, R13.2
unnamed: P2.4, R12.2
unnamed: P2.5, R11.2
unnamed: P2.6, R10.2
unnamed: Q1.1, R2.2
unnamed: Q2.1, R3.1
unnamed: Q3.1, R4.2
unnamed: Q4.1, R5.1
unnamed: Q5.1, R6.2
unnamed: Q6.1, R7.1
unnamed: R2.1, U6.7
unnamed: R3.2, U6.5
unnamed: R4.1, U7.7
unnamed: R5.2, U7.5
unnamed: R6.1, U5.7
unnamed: R7.2, U5.5

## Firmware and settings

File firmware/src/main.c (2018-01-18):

/*
 	bldc-drive Cheap and simple brushless DC motor driver designed for CNC applications using STM32 microcontroller.
	Copyright (C) 2015 Pekka Roivainen

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
	You should have received a copy of the GNU General Public License
	along with this program; if not, write to the Free Software
	Foundation, Inc., 51 Franklin Street, Fifth Floor, Boston, MA  02110-1301, USA.
*/


#include <stdint.h>
#include <stdio.h>
#include <stddef.h>

#include <stm32f10x_gpio.h>
#include <stm32f10x_tim.h>
#include <stm32f10x_rcc.h>
#include <stm32f10x_dma.h>
#include <stm32f10x_flash.h>



#include "pwm.h"
#include "hall.h"
#include "adc.h"
#include "input.h"
#include "encoder.h"
#include "pid.h"
#include "usart.h"
#include "configuration.h"
#include "input.h"
#include "utils.h"
volatile uint8_t dir;
volatile servoConfig s;


int main() {

	motor_running=0;
	updateCtr=0;
	dir=1;

	FLASH_Unlock();
	getConfig();
#ifdef SINUSOID_DRIVE
	//sinusoid always needs encoder.
	s.commutationMethod = commutationMethod_Encoder;
#endif

	initUSART(s.usart_baud);
	printConfiguration();
	systickInit(1000);
	initPWM();
	initADC();

	if( s.commutationMethod == commutationMethod_HALL)
	{
		initHALL();
	}

	if(s.inputMethod == inputMethod_stepDir)
	{
		initStepDirInput();
	}
	else if (s.inputMethod == inputMethod_pwmVelocity)
	{
		initPWMInput();
	}
	if(s.inputMethod == inputMethod_stepDir || s.commutationMethod == commutationMethod_Encoder)
	{
		initEncoder();
	}

	if(s.inputMethod == inputMethod_stepDir)
	{
		initPid();
	}
	initLeds();
	POWER_LED_ON;

	uint8_t ena;
	//check if ENA is on already at start. If it is, start motor.
if(!is_ena_inverted)
		ena = GPIO_ReadInputDataBit(GPIOA, GPIO_Pin_5);
else
		ena = (~(GPIO_ReadInputDataBit(GPIOA, GPIO_Pin_5)))&1;

	if(ena)
	{
		pwm_motorStart();
		ENABLE_LED_ON;
	}
	//two different types of main loops depending on commutation method
	if(s.commutationMethod == commutationMethod_Encoder || s.inputMethod == inputMethod_stepDir)
	{
		while (1)
		{

			  getEncoderCount();
#ifdef SINUSOID_DRIVE
			  pwm_setDutyCycle();
#endif



#ifndef SINUSOID_DRIVE
			  //check commutation position for trapezoid commutation if done by encoder
			  if(s.commutationMethod == commutationMethod_Encoder && encoder_commutation_pos != encoder_commutation_table[encoder_shaft_pos])
			  {

				  encoder_commutation_pos = encoder_commutation_table[encoder_shaft_pos];
				  pwm_Commute(encoder_commutation_pos);

			  }
#endif

			  if(serial_stream_enabled && DMA_GetFlagStatus(DMA1_FLAG_TC2) == SET)
			  {
				  //dma transfer is complete
				  usart_send_stream();
			  }

		}
    }
	else
	{
		while(1)
		{
			//commutation handled by HALL sensor interrupts in this case
			pwm_setDutyCycle();

			if(serial_stream_enabled && DMA_GetFlagStatus(DMA1_FLAG_TC2) == SET)
			{
				//dma transfer is complete
				usart_send_stream();
			}
		}
	}
}

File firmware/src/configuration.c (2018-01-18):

/*
 	bldc-drive Cheap and simple brushless DC motor driver designed for CNC applications using STM32 microcontroller.
	Copyright (C) 2015 Pekka Roivainen

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
	You should have received a copy of the GNU General Public License
	along with this program; if not, write to the Free Software
	Foundation, Inc., 51 Franklin Street, Fifth Floor, Boston, MA  02110-1301, USA.
*/


#include "configuration.h"
#include "eeprom.h"
#include "usart.h"
#include <string.h>
#include <stdio.h>
#define EADDR_IS_INITIALIZED 0x0001
#define EADDR_CONFIG_START 0x0002

void writeConfig()
{

	FLASH_Unlock();


	uint16_t i;
	int16_t *ptr = (int16_t *)&s;
	for(i=0; i<sizeof(servoConfig)/2;i++)
	{
		if(EE_WriteVariable(EADDR_CONFIG_START+i, *ptr)!=FLASH_COMPLETE)
		{
			usart_sendStr("Flash Error\n\r");
		}
		ptr++;
	}

	FLASH_Lock();

}
void getConfig()
{
	FLASH_Unlock();

	uint16_t i;

	uint16_t *ptr;
	EE_Init();
	EE_ReadVariable(EADDR_IS_INITIALIZED,&i);
	if(i != 0x5254)
	{
		//empty or corrupted EEPROM detected: write default config
		//EE_Format();
		EE_WriteVariable(EADDR_IS_INITIALIZED, 0x5254);
		s.commutationMethod = commutationMethod_Encoder;
		s.inputMethod = inputMethod_stepDir;
		s.encoder_PPR = 2400;
		s.encoder_poles = 7;
		s.encoder_counts_per_step = 1;
		s.invert_dirstepena = 7;
		s.max_error = 1000;
		s.pid_Kp = 10;
		s.pid_Ki = 0;
		s.pid_Kd = 0;
		s.pid_FF1 = 0;
		s.pid_FF2 = 0;
		s.pid_deadband = 0;
		s.max_current = 1000;
		s.usart_baud = 1152;
		s.commutation_offset=0;
		writeConfig();
		return;

	}
	ptr = (uint16_t *)&s;
	for(i=0; i<sizeof(servoConfig)/2;i++)
	{

		if(EE_ReadVariable(EADDR_CONFIG_START+i, ptr)!=0)
			usart_sendStr("Flash Error\n\r");
		ptr++;
	}
	FLASH_Lock();
	return;

}

void setConfig(char* param, int16_t value)
{
	if (strstr( param, "commutationMethod" ) != NULL)
	{
		s.commutationMethod = (uint16_t)value;
		//writeConfig();

		//this is taken into account on next boot
		//usart_sendStr("SET OK\n");

	}
	if (strstr( param, "inputMethod" ) != NULL)
	{
		s.inputMethod = (uint16_t)value;

		//usart_sendStr("SET OK\n");
	}
	if (strstr( param, "encoder_PPR" ) != NULL)
	{
		s.encoder_PPR = (uint16_t)value;

		//usart_sendStr("SET OK\n");
	}
	if (strstr( param, "encoder_poles" ) != NULL)
	{
		s.encoder_poles = (uint16_t)value;
		//usart_sendStr("SET OK\n");
	}
	if (strstr( param, "encoder_counts_per_step" ) != NULL)
	{
		s.encoder_counts_per_step = (uint16_t)value;

		//usart_sendStr("SET OK\n");
	}
	if (strstr( param, "pid_Kp" ) != NULL)
	{
		s.pid_Kp = (int16_t)value;

		//usart_sendStr("SET OK\n");
	}
	if (strstr( param, "pid_Ki" ) != NULL)
	{
		s.pid_Ki = (int16_t)value;

		//usart_sendStr("SET OK\n");
	}
	if (strstr( param, "pid_Kd" ) != NULL)
	{
		s.pid_Kd = (int16_t)value;

		//usart_sendStr("SET OK\n");
	}
	if (strstr( param, "pid_FF1" ) != NULL)
	{
		s.pid_FF1 = (int16_t)value;

		//usart_sendStr("SET OK\n");
	}
	if (strstr( param, "pid_FF2" ) != NULL)
	{
		s.pid_FF2 = (int16_t)value;

		//usart_sendStr("SET OK\n");
	}
	if (strstr( param, "pid_deadband" ) != NULL)
	{
		s.pid_deadband = (int16_t)value;

		//usart_sendStr("SET OK\n");
	}
	if (strstr( param, "usart_baud" ) != NULL)
	{
		s.usart_baud = (uint16_t)value;

		//usart_sendStr("SET OK\n");
	}
	if (strstr( param, "max_current" ) != NULL)
	{
		s.max_current = (uint16_t)value;

		//usart_sendStr("SET OK\n");
	}
	if (strstr( param, "max_error" ) != NULL)
	{
		s.max_error = (uint16_t)value;

		//usart_sendStr("SET OK\n");
	}
	if (strstr( param, "invert_dirstepena" ) != NULL)
	{
		s.invert_dirstepena = (uint16_t)value;

		//usart_sendStr("SET OK\n");
	}
	if (strstr( param, "commutation_offset" ) != NULL)
	{
		   s.commutation_offset = (uint16_t)value;

		   //usart_sendStr("SET OK\n");
	}

}
void printConfiguration()
{
	char buf[50];
	sprintf(buf,"commutationMethod: %d\n",s.commutationMethod);
	usart_sendStr(buf);
	sprintf(buf,"inputMethod: %d\n",s.inputMethod);
	usart_sendStr(buf);
	sprintf(buf,"encoder_PPR: %d\n",s.encoder_PPR);
	usart_sendStr(buf);
	sprintf(buf,"encoder_poles: %d\n",s.encoder_poles);
	usart_sendStr(buf);
	sprintf(buf,"encoder_counts_per_step: %d\n",s.encoder_counts_per_step);
	usart_sendStr(buf);
	sprintf(buf,"max_error: %d\n",s.max_error);
	usart_sendStr(buf);
	sprintf(buf,"invert_dirstepena: %d\n",s.invert_dirstepena);
	usart_sendStr(buf);
	sprintf(buf,"pid_Kp: %d\n",s.pid_Kp);
	usart_sendStr(buf);
	sprintf(buf,"pid_Ki: %d\n",s.pid_Ki);
	usart_sendStr(buf);
	sprintf(buf,"pid_Kd: %d\n",s.pid_Kd);
	usart_sendStr(buf);
	sprintf(buf,"pid_FF1: %d\n",s.pid_FF1);
	usart_sendStr(buf);
	sprintf(buf,"pid_FF2: %d\n",s.pid_FF2);
	usart_sendStr(buf);
	sprintf(buf,"pid_deadband: %d\n",s.pid_deadband);
	usart_sendStr(buf);
	sprintf(buf,"usart_baud: %d\n",s.usart_baud);
	usart_sendStr(buf);
	sprintf(buf,"max_current: %d\n",s.max_current);
	usart_sendStr(buf);
    sprintf(buf,"commutation_offset: %d\n",s.commutation_offset);
    usart_sendStr(buf);



}

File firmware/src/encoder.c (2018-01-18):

/*
 	bldc-drive Cheap and simple brushless DC motor driver designed for CNC applications using STM32 microcontroller.
	Copyright (C) 2015 Pekka Roivainen

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
	You should have received a copy of the GNU General Public License
	along with this program; if not, write to the Free Software
	Foundation, Inc., 51 Franklin Street, Fifth Floor, Boston, MA  02110-1301, USA.
*/



#include <stm32f10x_gpio.h>
#include <stm32f10x_tim.h>
#include <stm32f10x_rcc.h>

#include "encoder.h"
#include "usart.h"
#include "input.h"
#include "pwm.h"
#include "hall.h"
#include "utils.h"
#include "adc.h"
#include "math.h"

volatile int32_t encoder_count;

uint16_t encoder_shaft_pos; //this is the shaft position as encoder counts
uint16_t encoder_commutation_pos; //this is shaft position from the beginning of current commuatiton sequence.

#ifndef SINUSOID_DRIVE
uint8_t encoder_commutation_table[4096]; //20 poles max //8096 PPR max at the moment.
#else
int16_t sine_table[4096]; //the required length of sine_table is encoder_ppr/number_of_poles, so this allows quite high ppr encoder..
uint16_t commutation_length; //how many encoder steps there are per commutation circle (i.e encoder_ppr/motor_poles)
#endif

volatile uint16_t encoder_lastCount;

//uint16_t findNextEncoderCommutationCNT(int8_t dir);
void buildCommutationTable()
{
	uint16_t i;
#ifndef SINUSOID_DRIVE
	for(i=0;i<s.encoder_PPR;i++)
	{
		encoder_commutation_table[i] = commutation_sequence[(i*s.encoder_poles*6/s.encoder_PPR) % 6];

	}
#else
	commutation_length = s.encoder_PPR/s.encoder_poles;
	for(i=0;i<commutation_length;i++)
	{
		sine_table[i] = (int16_t)(sinf((float)i/(float)commutation_length*2*M_PI)*(float)SINE_TABLE_MAX);
	}

#endif
}

#ifndef SINUSOID_DRIVE
void forcedInitialization()
{
	//during initialization the positive voltage will be applied to Channel1 and negative to Channel3. This will move the rotor to commutation position 1
	if(motor_running)
		return;


	TIM_SelectOCxM(TIM1, TIM_Channel_1, TIM_OCMode_PWM1);
	TIM_CCxCmd(TIM1, TIM_Channel_1, TIM_CCx_Enable);
	TIM_CCxNCmd(TIM1, TIM_Channel_1, TIM_CCxN_Enable);

	TIM_SelectOCxM(TIM1, TIM_Channel_2, TIM_ForcedAction_InActive);
	TIM_CCxNCmd(TIM1, TIM_Channel_2, TIM_CCxN_Enable);

	TIM_SelectOCxM(TIM1, TIM_Channel_3, TIM_ForcedAction_Active);
	TIM_CCxNCmd(TIM1, TIM_Channel_3, TIM_CCxN_Enable);
	uint16_t i;
	for(i=0;i<1000;i++)
	{
		TIM1->CCR1=i;
		TIM1->CCR2=i;
		TIM1->CCR3=i;
		delay_ms(1);
	}
	delay_ms(10);
	TIM_SetCounter(ENCODER_TIM,0);
	encoder_count=0;
	encoder_lastCount=0;
	encoder_shaft_pos=0;

	delay_ms(1);
	TIM1->CCR1=0;
	TIM1->CCR2=0;
	TIM1->CCR3=0;


}
#else
void forcedInitialization()
{
	//apply positive voltage (PWM) to phase B and negative to phase C. (Commutation table starts from that position)
	if(motor_running)
		return;


	//TIM_SelectOCxM(TIM1, TIM_Channel_1, TIM_ForcedAction_InActive);
	TIM_CCxCmd(TIM1, TIM_Channel_1, TIM_CCx_Disable);
	TIM_CCxNCmd(TIM1, TIM_Channel_1, TIM_CCxN_Disable);

	TIM_SelectOCxM(TIM1, TIM_Channel_3, TIM_OCMode_PWM1);
	TIM_CCxCmd(TIM1, TIM_Channel_3, TIM_CCx_Enable);
	TIM_CCxNCmd(TIM1, TIM_Channel_3, TIM_CCxN_Enable);

	TIM_SelectOCxM(TIM1, TIM_Channel_2, TIM_ForcedAction_Active);
	TIM_CCxNCmd(TIM1, TIM_Channel_2, TIM_CCxN_Enable);

	uint16_t i;
	for(i=2000;i<4000;i++)
	{
		//increase duty until ADC kicks in
		if(i>max_duty)
		{
			TIM1->CCR1=max_duty;
			TIM1->CCR2=max_duty;
			TIM1->CCR3=max_duty;
		}
		else
		{
			TIM1->CCR1=i;
			TIM1->CCR2=i;
			TIM1->CCR3=i;
		}
		delay_ms(1);
	}
	delay_ms(100);
	TIM_SetCounter(ENCODER_TIM,0);
	encoder_count=0;
	encoder_lastCount=0;
	encoder_shaft_pos=0;

	delay_ms(1);
	pwm_motorStop();


}
#endif

void initEncoder()
{
	GPIO_InitTypeDef GPIO_InitStructure;
	RCC_APB2PeriphClockCmd(RCC_APB2Periph_GPIOA | RCC_APB2Periph_GPIOB, ENABLE);
if( ENCODER_TIM==TIM2)
{
#ifndef ENCODER_TIM2_REMAP
	RCC_APB1PeriphClockCmd(RCC_APB1Periph_TIM2,ENABLE);
	GPIO_InitStructure.GPIO_Pin = GPIO_Pin_0 | GPIO_Pin_1;
	GPIO_InitStructure.GPIO_Mode = GPIO_Mode_IPU;
	GPIO_InitStructure.GPIO_Speed = GPIO_Speed_50MHz;
	GPIO_Init(GPIOA, &GPIO_InitStructure);
#else
	RCC_APB1PeriphClockCmd(RCC_APB1Periph_TIM2,ENABLE);
	GPIO_InitStructure.GPIO_Pin = GPIO_Pin_15;
	GPIO_InitStructure.GPIO_Mode = GPIO_Mode_IPU;
	GPIO_InitStructure.GPIO_Speed = GPIO_Speed_50MHz;
	GPIO_Init(GPIOA, &GPIO_InitStructure);

	GPIO_InitStructure.GPIO_Pin = GPIO_Pin_3;
	GPIO_InitStructure.GPIO_Mode = GPIO_Mode_IPU;
	GPIO_InitStructure.GPIO_Speed = GPIO_Speed_50MHz;
	GPIO_Init(GPIOB, &GPIO_InitStructure);


	RCC_APB2PeriphClockCmd(RCC_APB2Periph_AFIO,ENABLE);
	GPIO_PinRemapConfig(GPIO_Remap_SWJ_JTAGDisable, ENABLE);
	GPIO_PinRemapConfig(GPIO_PartialRemap1_TIM2, ENABLE);


#endif

} else
{
	RCC_APB1PeriphClockCmd(RCC_APB1Periph_TIM4,ENABLE);
	GPIO_InitStructure.GPIO_Pin = GPIO_Pin_6 | GPIO_Pin_7;
	GPIO_InitStructure.GPIO_Mode = GPIO_Mode_IPU;
	GPIO_InitStructure.GPIO_Speed = GPIO_Speed_50MHz;
	GPIO_Init(GPIOB, &GPIO_InitStructure);
}

	TIM_DeInit(ENCODER_TIM);

	TIM_TimeBaseInitTypeDef timerInitStructure;
	TIM_TimeBaseStructInit(&timerInitStructure);
	timerInitStructure.TIM_Prescaler = 0;
	timerInitStructure.TIM_CounterMode = TIM_CounterMode_Up;
	timerInitStructure.TIM_Period = 0xFFFF;
	timerInitStructure.TIM_ClockDivision = 0;
	timerInitStructure.TIM_RepetitionCounter = 0;
	TIM_TimeBaseInit(ENCODER_TIM, &timerInitStructure);


	TIM_EncoderInterfaceConfig (ENCODER_TIM, TIM_EncoderMode_TI12,
								  TIM_ICPolarity_Rising,
								  TIM_ICPolarity_Rising);



	TIM_Cmd(ENCODER_TIM, ENABLE);


	if(s.commutationMethod == commutationMethod_Encoder)
	{
		buildCommutationTable();
		forcedInitialization();
	}
	if(s.commutationMethod == commutationMethod_HALL)
	{
	encoder_count=0;
	encoder_lastCount=0;
	encoder_shaft_pos=0;



	}


}

void getEncoderCount()
{
	uint16_t now = ENCODER_TIM->CNT;
	int16_t delta = (int16_t)(now - encoder_lastCount);
	encoder_lastCount = now;

	encoder_count += delta;

	//encoder_full_rounds = encoder_count / s.encoder_PPR;
	int16_t shaft_pos_tmp = (encoder_count+ s.commutation_offset ) % s.encoder_PPR;
	if(shaft_pos_tmp < 0)
		encoder_shaft_pos = s.encoder_PPR + shaft_pos_tmp;
	else
		encoder_shaft_pos = shaft_pos_tmp;

#ifdef SINUSOID_DRIVE
	encoder_commutation_pos = encoder_shaft_pos % commutation_length;
#endif

}

#ifdef SINUSOID_DRIVE
uint16_t getCommutationPos(uint8_t phase)
{
	//if driving forward, the commutation must lead the actual position by 90 degrees
	//if driving backward, the commutation must lag the actual position by 90 degrees
	int32_t tmp;
	if(dir)
	{
		tmp = (encoder_commutation_pos - commutation_length/4 + commutation_length*phase/3);
		if (tmp<0)
		{
			tmp+=commutation_length;
		}
		return (uint16_t)(tmp % commutation_length);

	}
	else
	{
		tmp= (encoder_commutation_pos + commutation_length/4 + commutation_length*phase/3);
		if (tmp<0)
		{
			tmp+=commutation_length;
		}
		return (uint16_t)(tmp % commutation_length);

	}
}
#endif

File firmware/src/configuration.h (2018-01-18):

/*
 	bldc-drive Cheap and simple brushless DC motor driver designed for CNC applications using STM32 microcontroller.
	Copyright (C) 2015 Pekka Roivainen

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
	You should have received a copy of the GNU General Public License
	along with this program; if not, write to the Free Software
	Foundation, Inc., 51 Franklin Street, Fifth Floor, Boston, MA  02110-1301, USA.
*/


#ifndef CONFIGURATION_H_
#define CONFIGURATION_H_

#include <stdint.h>


/*
 * functionality from sinusoid_drive branch has been merged to master brach 13.2.2017. define SINUSOID_DRIVE to
 * enable sinusoid commutation, comment it out to define trapezoidal commutation.
 *
 */

#define SINUSOID_DRIVE 1

//PID timer period. Counter runs at 1MHz, so f_pid = 1e6/period. 250=4kHz, 125=8Khz, 63=16kHz..
#define PID_TIM_PERIOD 40

//BLDC_CHOPPER_PERIOD defines the PWM clock frequency. Timer runs at 72MHz (Fcpu), so Fpwm = 72e6/period
//4000 = 18kHz
//2000 = 36kHz
#define BLDC_CHOPPER_PERIOD 2000
#ifndef SINUSOID_DRIVE
#define MAX_DUTY BLDC_CHOPPER_PERIOD-50 //100% duty not allowed to allow recharge of high side gate drivers
#else
#define ZERO_DUTY BLDC_CHOPPER_PERIOD/2
#define MAX_DUTY BLDC_CHOPPER_PERIOD/2-50 //100% duty not allowed to allow recharge of high side gate drivers
#endif

#define BLDC_NOL 7//Non-OverLapping, number of clock cycles
#define BLDC_DELAY 100 //Commutation delay. 1= no delay, 2000=7ms.




#define inputMethod_stepDir 1
#define inputMethod_pwmVelocity 2
#define commutationMethod_HALL 1
#define commutationMethod_Encoder 2

#define is_ena_inverted (s.invert_dirstepena>>0)&1
#define is_step_inverted (s.invert_dirstepena>>1)&1
#define is_dir_inverted (s.invert_dirstepena>>2)&1

typedef struct  {
	volatile uint16_t inputMethod;
	volatile uint16_t commutationMethod;
	volatile uint16_t encoder_PPR;
	volatile uint16_t encoder_poles;
	volatile uint16_t max_error;
	volatile uint16_t invert_dirstepena;
	volatile int16_t encoder_counts_per_step;
	volatile uint16_t max_current;
	volatile int16_t pid_Kp;
	volatile int16_t pid_Ki;
	volatile int16_t pid_Kd;
	volatile int16_t pid_FF1;
	volatile int16_t pid_FF2;
	volatile uint16_t pid_deadband;
	volatile int16_t commutation_offset;

	volatile uint16_t usart_baud; //baud divided by 100 to fit to 16 bits! for example 115200 => 1152

} servoConfig;
void getConfig();

void setConfig(char* param, int16_t value);
void writeConfig();
void printConfiguration();
#endif /* CONFIGURATION_H_ */

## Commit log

2015-11-14 GPLv2 license information added
    [configuration.h]
2015-11-14 added hardware
    [bldc_control_ver1.kicad_pcb, bldc_control_ver1.sch, bldc_drive.kicad_pcb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]
2015-11-15 added pdfs of schematics
2015-11-15 Cleanup + bug fixes in PWM input mode
    [configuration.h]
2016-05-01 Major firmware update
    [configuration.h]
2016-05-26 PCB ver2. Added Gui
    [Alu_casing.kicad_pcb, bldc_control_ver2.csv, bldc_control_ver2.kicad_pcb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]
2016-08-29 Serial streaming added for encoder commutation mode
2016-09-08 Deleted hall.h, not needed in sinusoid
2016-09-08 adding hall.h
2016-09-08 bugfix: s.max_error did not have any effect
    [pid.c]
2017-02-20 first: remove old versions of the hardware - git history rulez. second: made schematic a bit more readable... third: migrated schematic to KiCAD 4
    [bldc_control_ver1.kicad_pcb, bldc_control_ver1.sch, bldc_control_ver2.sch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]
2017-02-20 tempfiles vom KiCAD entfernt und Bauteilwerte ausgedacht...
    [bldc_control_ver2.csv, bldc_control_ver2.sch]
2017-02-20 schaltplan und layout angepasst
    [bldc_control_ver2.kicad_pcb, bldc_control_ver2.sch]
2017-02-21 hardware: bldc_control_v3 release. firmware: combined the sinusoid_drive branch to master. select between trapezoidal commutation and sinusoid drive in configuration.h
    [bldc_control_ver3.kicad_pcb, bldc_control_ver3.sch, configuration.h]
2018-01-18 Misc. refactoring and improvements. Added pid_deadband parameter.
    [configuration.h]

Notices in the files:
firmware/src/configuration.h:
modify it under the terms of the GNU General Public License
